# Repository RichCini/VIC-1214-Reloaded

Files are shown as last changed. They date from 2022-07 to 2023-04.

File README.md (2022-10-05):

# VIC-1214-Reloaded
Reimplementation of a voice synthesizer board I built in 1981.

The voice synthsizer is a user-port peripheral based on
a circuit design from the original Radio Shack/GI
data sheet (my original design), an article in BYTE (and
for which I can't find the reference; I only have the scan),
and a circuit in the Commodore 64 Interfacing Blue Book (which
had a nice test program). There is a project called retroSpeak
from jbeuckm (albeit an add-on for a Raspberry Pi) that uses an
external programmable clock rather than a crystal.

The Canonical List of Commodore Products lists a VIC-1214
Speech Synthesizer cartridge, but I have not been able to
locate any information on it. Several 3rd party companies
made an expansion port cartridge synthisizer such as the
VicTalker (SSI263 chip), the Adman (SP0256), the
Chatterbox, and the PPP SpeakEasy (SSI).

I tried a using a replacable TTL oscillator rather than
a crystal with the coupling circuit from jbeuckm's design,
but it didn't work. I suspect that the signal phase is
wrong, but until I test it with my Silgent waveform
generator, I won't know. I think it needs an inverted
clock in order to work. So, the existing design uses
the tried-and-true crystal for now. Changing the crystal
frequency will change the pitch of the voice, so even a
colorburst crystal (3.59MHz) will work.

I had a few sample boards made and it works flawlessly with
the LM386 amplifier. Glad to see it worked the first time!

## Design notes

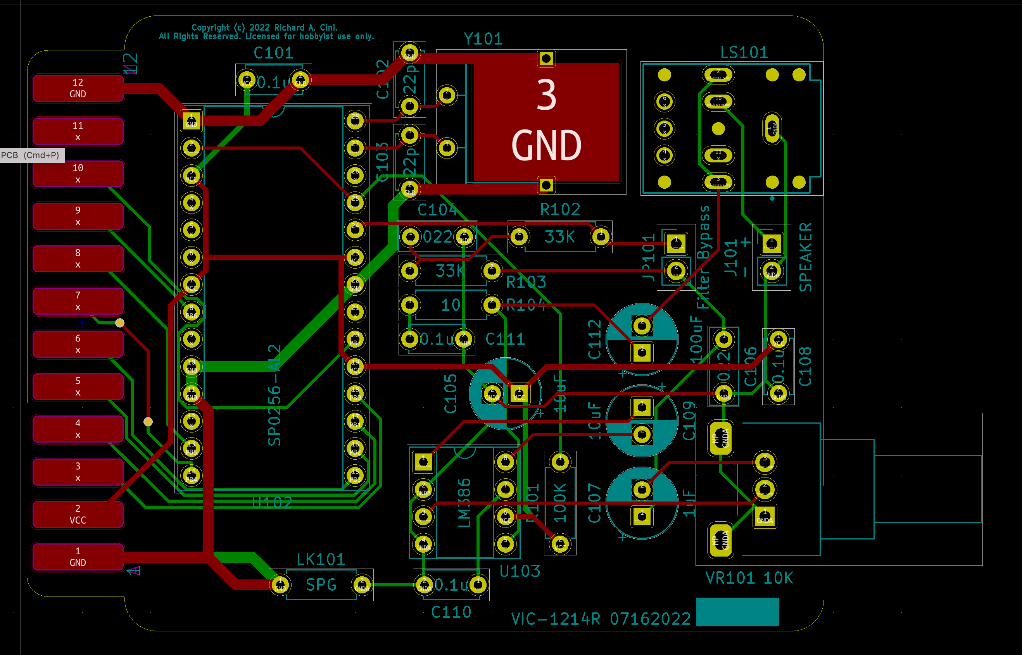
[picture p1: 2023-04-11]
Screen Shot 2022-08-02 at 9.37.52 PM.png

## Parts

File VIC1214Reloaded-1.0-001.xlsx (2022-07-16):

Source: | /Users/racini/Documents/KiCad/VIC1214Reloaded-1.0-001/vic1214.kicad_sch
Date: | Saturday, July 16, 2022 at 10:30:45 AM
Tool: | Eeschema (6.0.4-0)
Generator: | /Applications/KiCad/KiCad.app/Contents/SharedSupport/plugins/bom_csv_grouped_by_value_with_fp.py
Component Count: | 26
Item | Qty | Order | Reference(s) | Value | Description | Footprint | Mouser Part Number
1 | 4 |  | C101, C107, C109, C110 | 0.1uF/50v | 0.1uF/50v X7R | Capacitor_THT:C_Disc_D5.0mm_W2.5mm_P5.00mm | K104K15X7RF53H5
2 | 2 |  | C102, C105 | 22nF/.022uF | 22nF/50v MLC | Capacitor_THT:C_Disc_D7.0mm_W2.5mm_P5.00mm | 810-FG28X7R1H223KNT0
3 | 1 |  | C103 | 47pF | 47pF/50v MLC | Capacitor_THT:C_Disc_D5.0mm_W2.5mm_P5.00mm | 810-FG28C0G1H470JNT0
4 | 2 |  | C104, C108 | 10uF/50v | 10uF/50v | Capacitor_THT:CP_Radial_D6.3mm_P2.50mm | 50ML10MEFC5X7
5 | 1 |  | C106 | 1uF/50v | 1uF/50v | Capacitor_THT:CP_Radial_D6.3mm_P2.50mm | UMA1H010MDD
6 | 1 |  | C111 | 100uF/16v | 100uF/16v | Capacitor_THT:CP_Radial_D6.3mm_P2.50mm | 667-ECE-A1CKA101 710-860080373005
7 | 1 |  | J101 | JACK 3.5MM | Audio Jack, 3 Poles (Stereo / TRS), Switched TR Poles (Normalling) | Connector_Audio:Jack_3.5mm | 490-SJ-3568N
8 | 1 |  | JP101 | Filter Bypass | Jumper, 2-pole, open
9 | 1 |  | LK101 | Link | wire jumper for single point GND
10 | 1 |  | LS101 | SPEAKER | Speaker, off-board pin header
11 | 1 |  | R101 | 100.0KQ | 100k, 1/4w
12 | 2 |  | R102, R106 | 10Q | 10 ohm, 1/4w
13 | 2 |  | R103, R105 | 33.0KQ | 33k, 1/4w
14 | 1 |  | R104 | 10.0KQ | 10k, 1/4w
15 | 1 |  | U102 | SP0256-AL2 | GI speech chip
16 | 1 |  | U103 | LM386 | LM386 audio amplifier |  | 926-LM386N-4/NOPB
17 | 1 |  | VR101 | 10K audio pot | Potentiometer with a mounting pin | Potentiometer_Alps_RK09L_Single_Horizontal | 688-RK097111080R
18 | 1 |  | X101 | CXO 3.12MHz | Oscillator, half-can | Use color burst 3.579545MHz but pitch of voice will be slightly different. | 520-TCH357-X
19 | 1 |  | DIP socket | DIP8
20 | 1 |  | DIP socket | DIP28
21 | 1 |  | OSC8 socket | OSC8 | half-can oscillator socket

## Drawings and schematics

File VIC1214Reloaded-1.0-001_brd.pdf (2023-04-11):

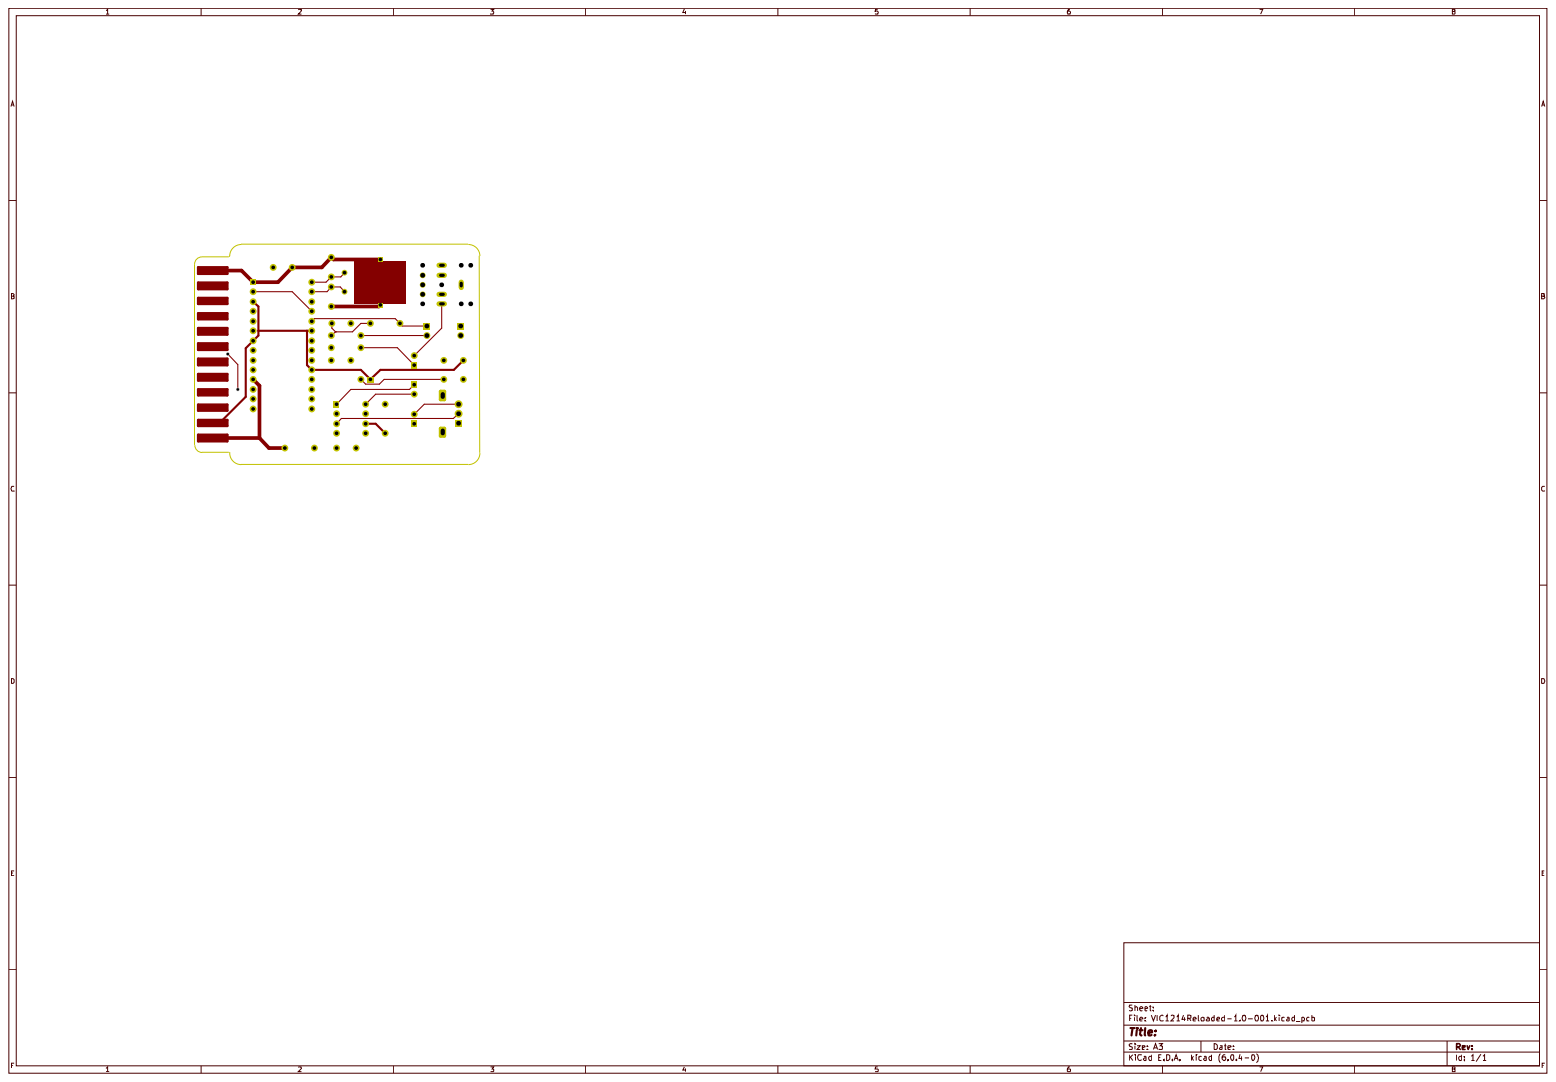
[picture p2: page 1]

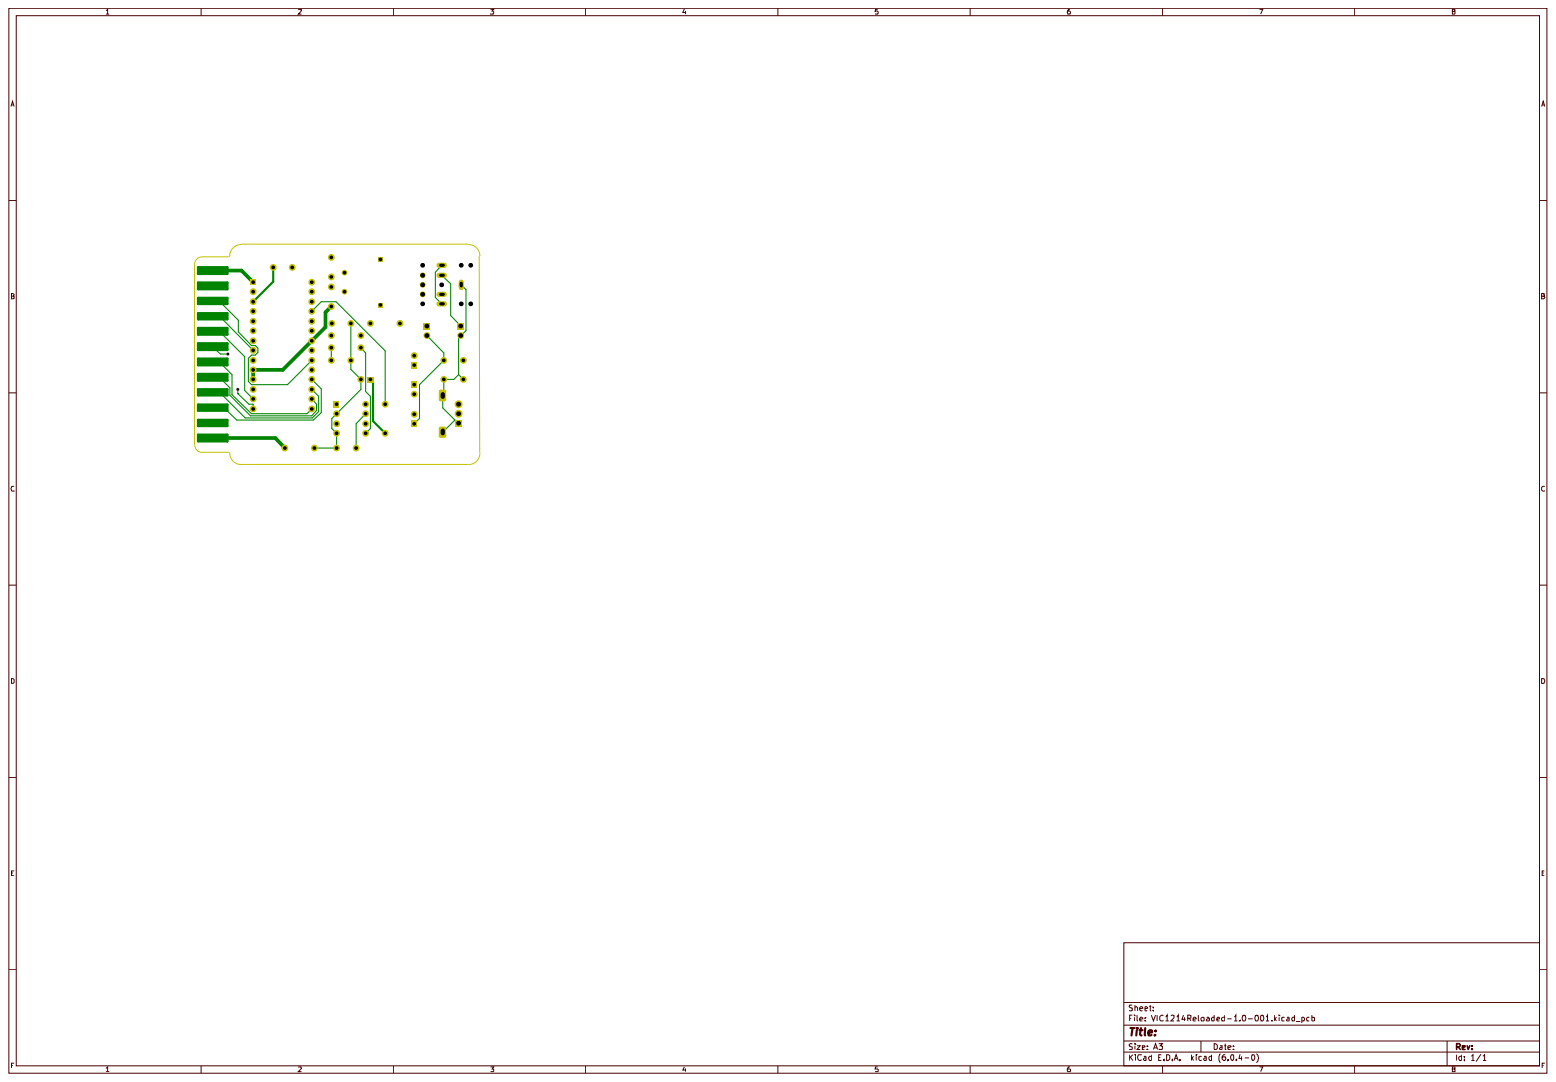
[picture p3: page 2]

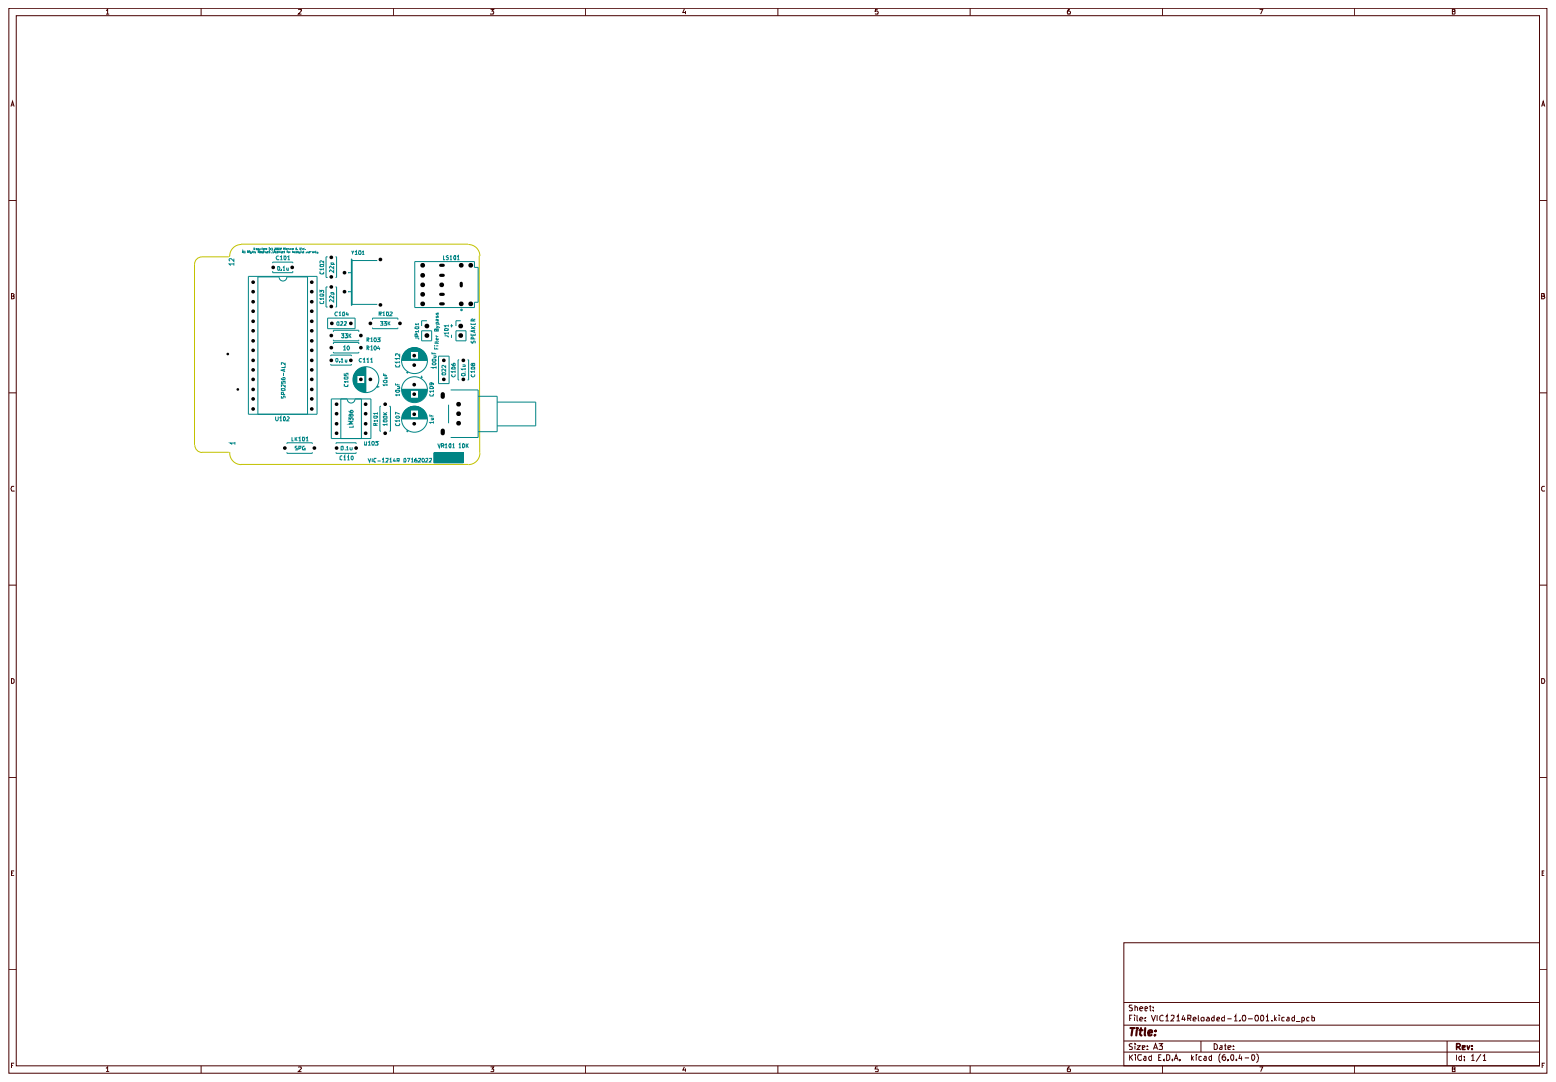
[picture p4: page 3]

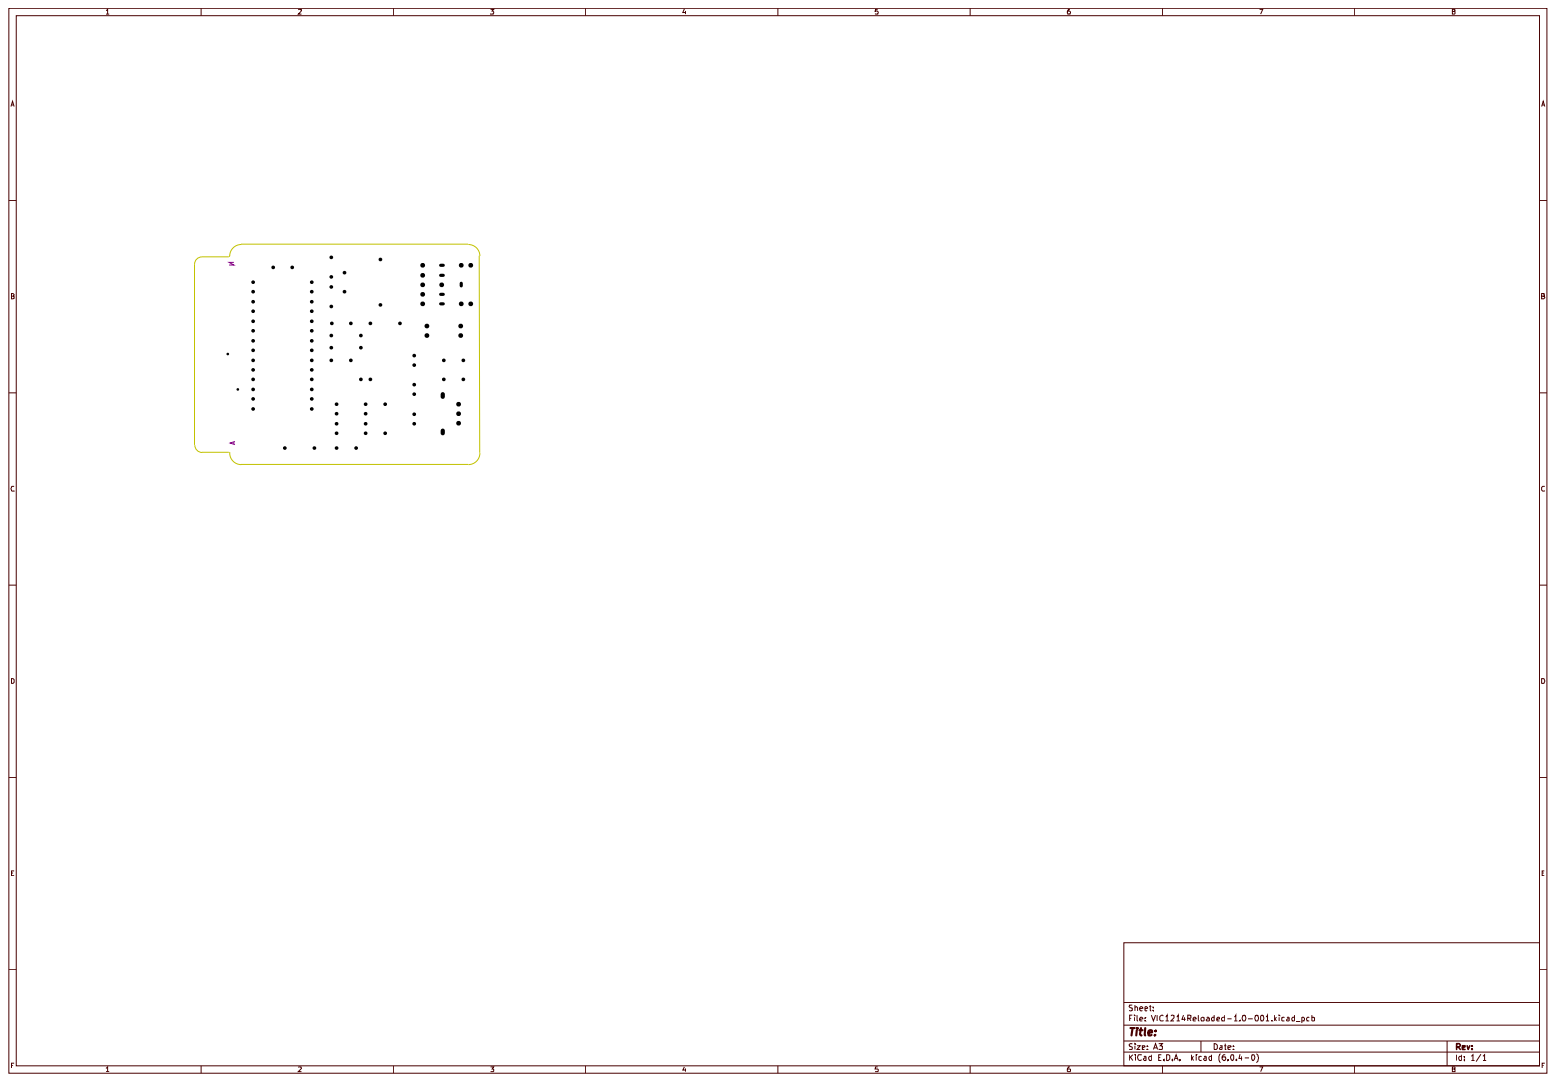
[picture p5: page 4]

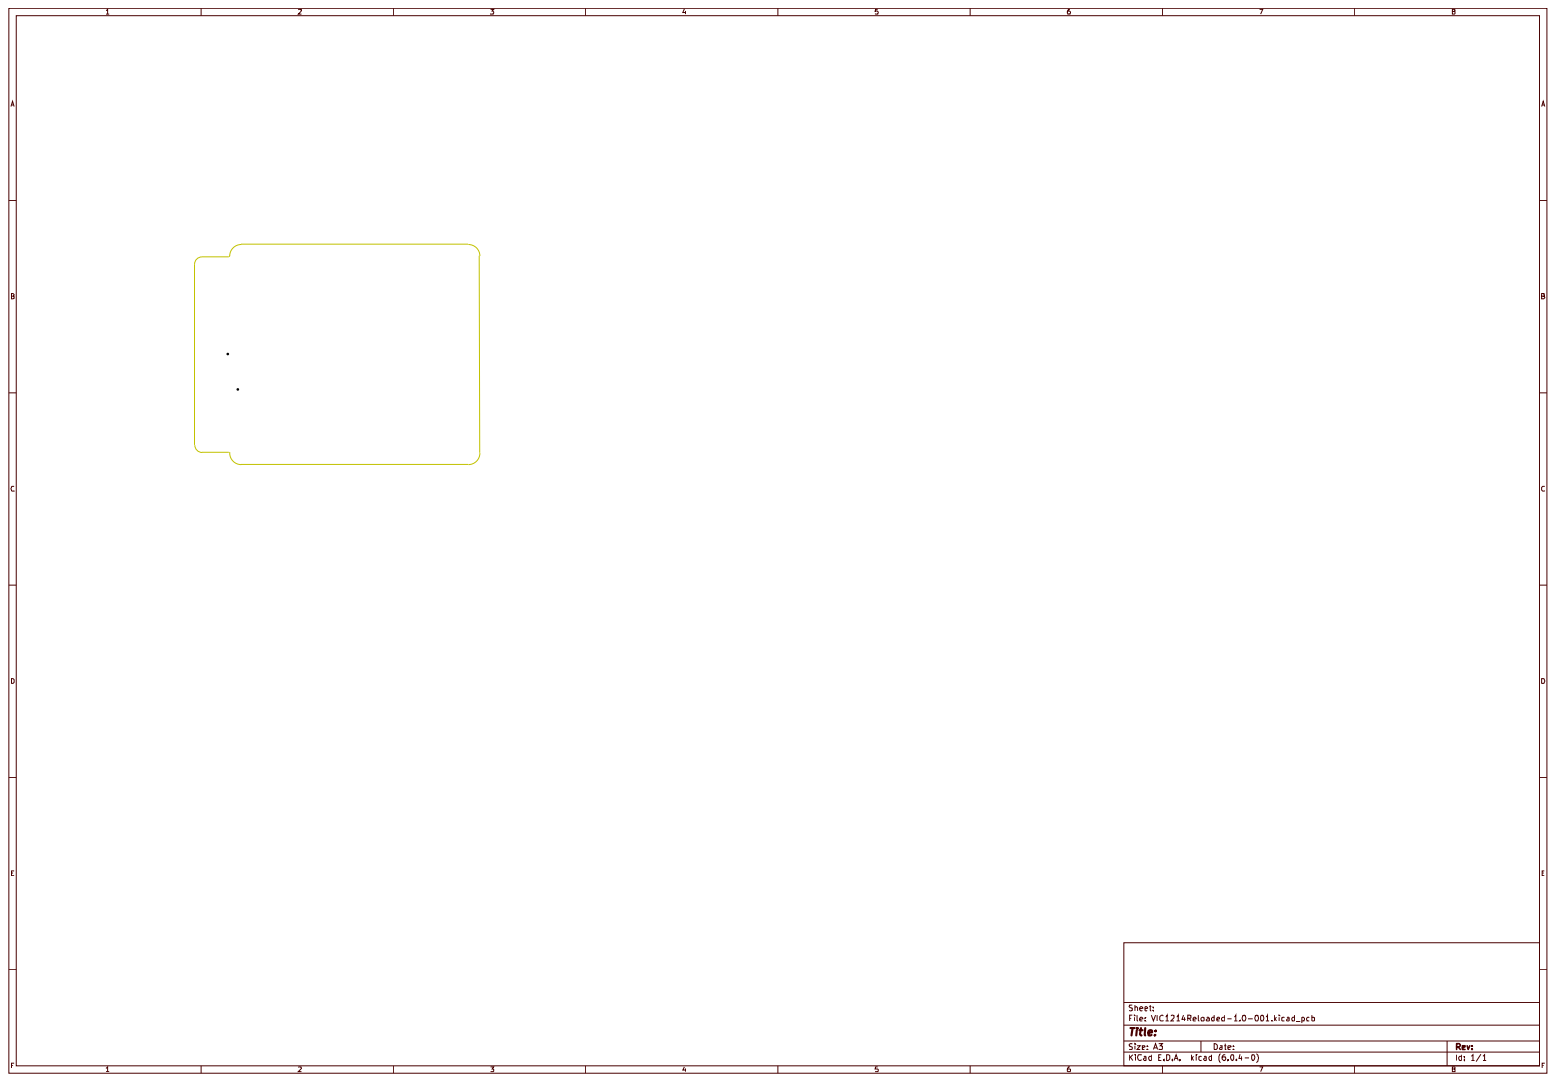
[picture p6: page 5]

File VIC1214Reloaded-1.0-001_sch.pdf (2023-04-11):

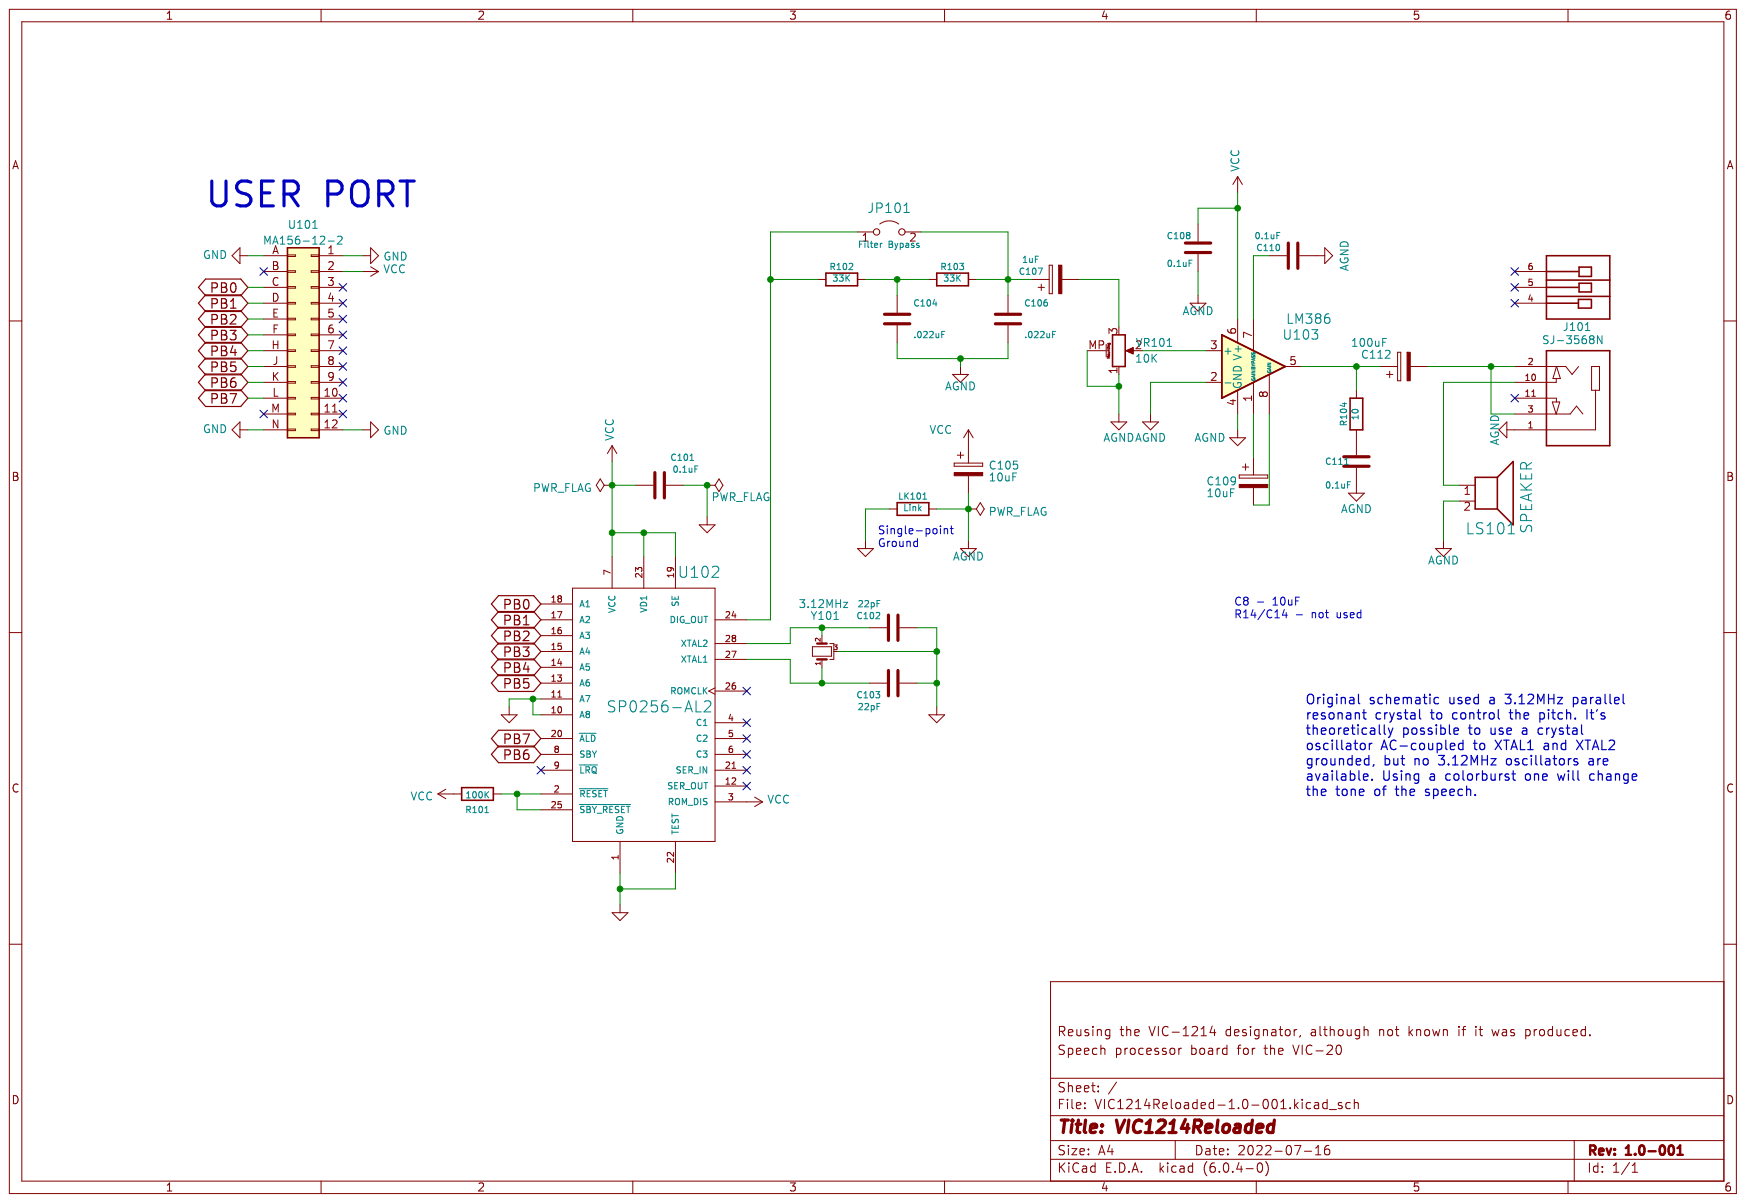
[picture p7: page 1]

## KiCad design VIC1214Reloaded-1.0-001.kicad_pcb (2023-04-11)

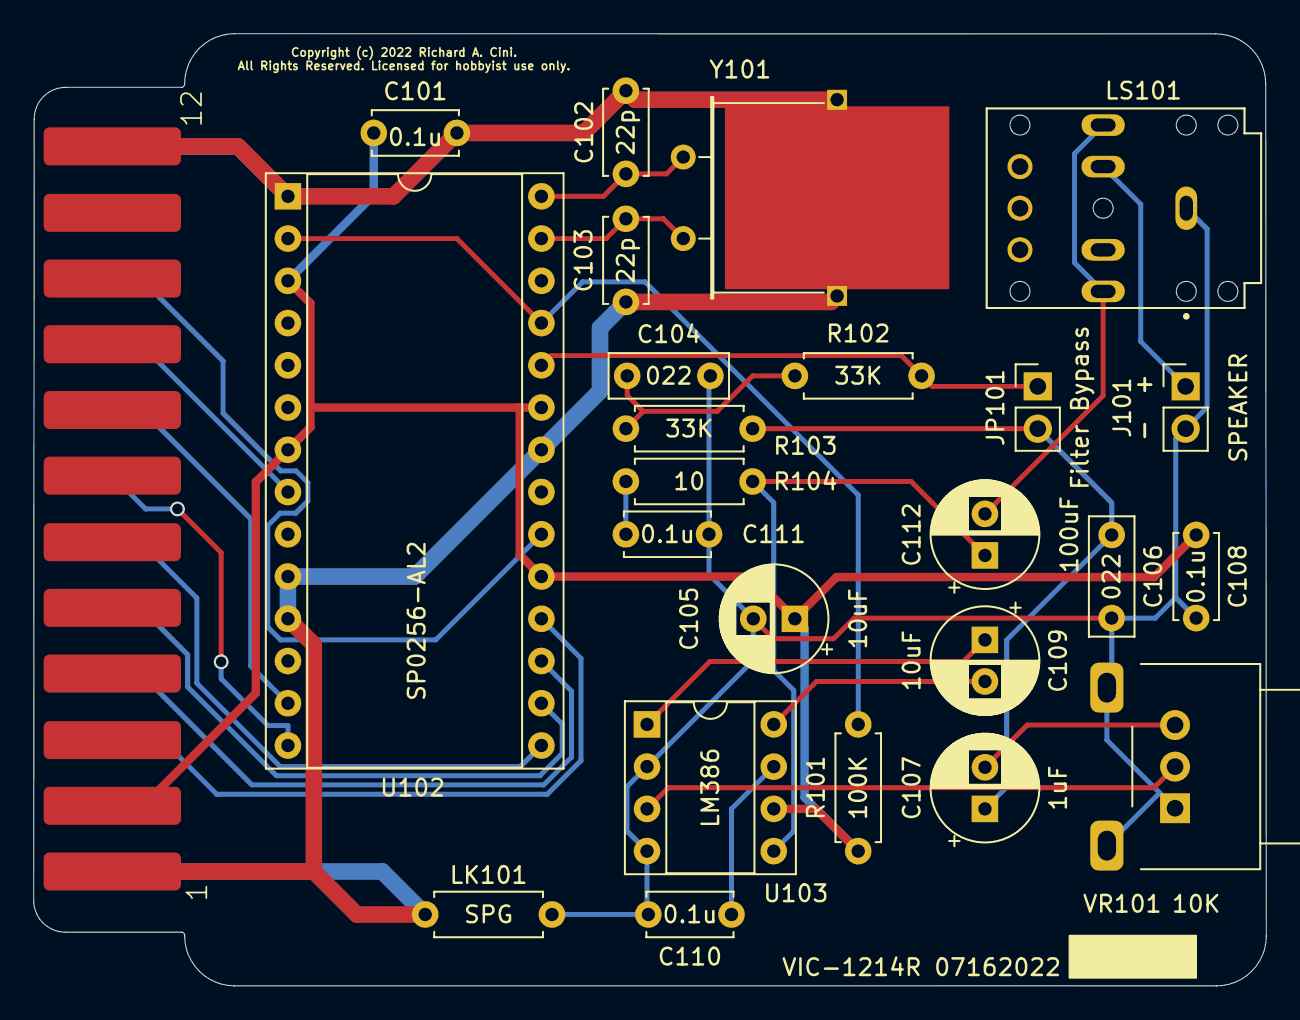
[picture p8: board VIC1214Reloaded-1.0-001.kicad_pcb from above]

Board: 2 copper layers, 74.1 x 57.3 mm, 25 parts (0 on the bottom side), 26 nets.

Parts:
C101, C108, C110, C111: 0.1u; C_Disc_D5.0mm_W2.5mm_P5.00mm
C102, C103: 22p; C_Disc_D5.0mm_W2.5mm_P5.00mm
C104, C106: 022; C_Disc_D7.0mm_W2.5mm_P5.00mm
C105, C109: 10uF; CP_Radial_D6.3mm_P2.50mm
C107: 1uF; CP_Radial_D6.3mm_P2.50mm
C112: 100uF; CP_Radial_D6.3mm_P2.50mm
J101: SJ-3568N; CUI_SJ-3568N
JP101: Filter Bypass; PinHeader_1x02_P2.54mm_Vertical
LK101: Link; R_Axial_DIN0207_L6.3mm_D2.5mm_P7.62mm_Horizontal
LS101: SPEAKER; PinHeader_1x02_P2.54mm_Vertical
R101: 100K; R_Axial_DIN0207_L6.3mm_D2.5mm_P7.62mm_Horizontal
R102, R103: 33K; R_Axial_DIN0207_L6.3mm_D2.5mm_P7.62mm_Horizontal
R104: 10; R_Axial_DIN0207_L6.3mm_D2.5mm_P7.62mm_Horizontal
U101: MA156-12-2; MA156-12-2-Peripheral
U102: SP0256-AL2; DIP-28_W15.24mm_Socket
U103: LM386; DIP-8_W7.62mm_Socket
VR101: 10K; Potentiometer_Alps_RK09L_Single_Horizontal
Y101: 3.12MHz; Crystal_HC49-U_Horizontal_1EP_style2

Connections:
GND: C101.2, C102.2, C103.2, LK101.1, U101.1, U101.12, U101.A, U101.N, U102.1 (GND), U102.10 (A8), U102.11 (A7), U102.22 (TEST), Y101.3
GNDA: C104.2, C105.2, C106.2, C108.2, C110.2, C111.2, J101.1, LK101.2, LS101.2, U103.2 (-), U103.4 (GND), VR101.1, VR101.MP (MountPin)
unnamed: C102.1, U102.28 (XTAL2), Y101.2
unnamed: C103.1, U102.27 (XTAL1), Y101.1
unnamed: C104.1, R102.2, R103.1
unnamed: C106.1, C107.1, JP101.2 (B), R103.2
unnamed: C107.2, VR101.3
unnamed: C109.1, U103.1 (GAIN)
unnamed: C109.2, U103.8 (GAIN)
unnamed: C110.1, U103.7 (BYPASS)
unnamed: C111.1, R104.1
unnamed: C112.1, R104.2, U103.5
unnamed: C112.2, J101.2, J101.3
unnamed: J101.10, LS101.1
unnamed: JP101.1 (A), R102.1, U102.24 (DIG_OUT)
unnamed: R101.1, U102.2 (~RESET), U102.25 (~SBY_RESET)
unnamed: U103.3 (+), VR101.2
PB0: U101.C, U102.18 (A1)
PB1: U101.D, U102.17 (A2)
PB2: U101.E, U102.16 (A3)
PB3: U101.F, U102.15 (A4)
PB4: U101.H, U102.14 (A5)
PB5: U101.J, U102.13 (A6)
PB6: U101.K, U102.8 (SBY)
PB7: U101.L, U102.20 (~ALD)
VCC: C101.1, C105.1, C108.1, R101.2, U101.2, U102.3 (ROM_DIS), U102.7 (VCC), U102.19 (SE), U102.23 (VD1), U103.6 (V+)

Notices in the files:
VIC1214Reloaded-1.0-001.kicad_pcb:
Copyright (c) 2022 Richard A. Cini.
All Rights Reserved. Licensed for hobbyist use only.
